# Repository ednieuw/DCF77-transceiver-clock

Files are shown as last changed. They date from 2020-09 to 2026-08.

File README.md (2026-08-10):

# DCF77 HC-12 Bluetooth transceiver clock

<table  border="0">
  <tr>
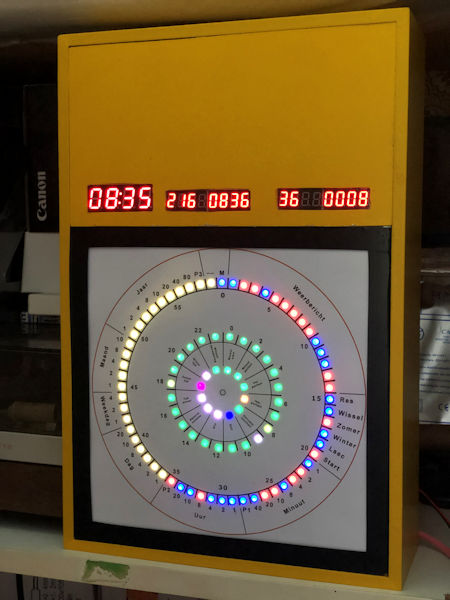
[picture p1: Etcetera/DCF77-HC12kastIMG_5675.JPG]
    <td></td>
    <td>
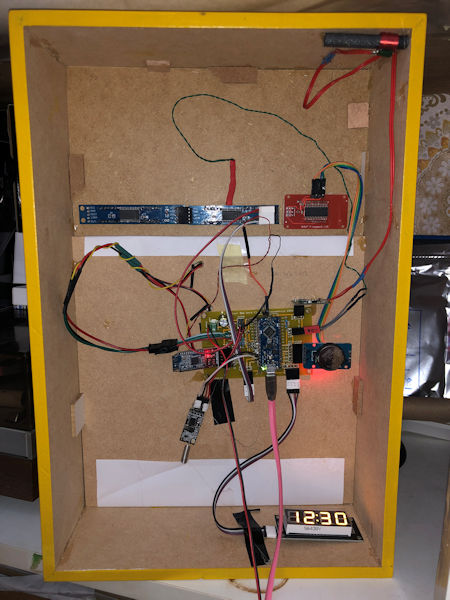
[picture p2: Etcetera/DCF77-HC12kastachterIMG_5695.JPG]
	</td>
  </tr>
  <tr class="auto-style1">
    <td>Front <span class="style7">(The colours of the LEDs are in real much more vivid) </span></td>
    <td>Inside the clock (3:55 hours later) <br>
    The DCF77-receiver hangs 10 cm away from the signal interfering LEDs and segment displays</td>
  </tr>
</table>
<p class="auto-style1"><strong>Introduction </strong></p>
<p class="auto-style1">This clock <a href="https://www.dcf77logs.de/live">decodes the DCF77-signal</a>, displays the received DCF77 bits and various information parameters in three WS2812 RGB-rings.<br>
  After decoding it sends the time as a string into the ether with a HC-12 433MHz Wireless Serial Transceiver.<br>
  with a Bluetooth module the clock can be controlled and statistics about the received signals retrieved 
  <br>
  The time is displayed with a 4-digit 7-segment
  HK16K33 and a 4-digit 7-segment
  I2C-TM1637  display.<br>
  (I prefer the TM1637 displays but bought the by accident HK16K33 displays.) <br>
  The received or calculated information is displayed with MAX7219 8-digits 7-segment displays. <br>
  <br>
  The software makes use of an algorithm that collects the readings without using interrupts (DCFNoInt) in contrast with the DCF77 Arduino library that uses interrupt to detect a pulse change. <br>
  In this DCFNoInt-program the processor is able to collect, in it spare time, over 30,000 
low or high signals.<br>
  In Mainflingen, Germany, a transmitter send on the long wave frequency of 77.5 KHz 
a signal that can be on or off (high or low). <br>
  Every second the signal is on for 0.1 second or 0.2 second.
That translates in respectively a 0 or 1 bit. <br>
The time is decoded in a <a href="https://en.wikipedia.org/wiki/Binary-coded_decimal">binary-coded decimal</a> format as shown in the picture below. </p>
<p class="auto-style1">
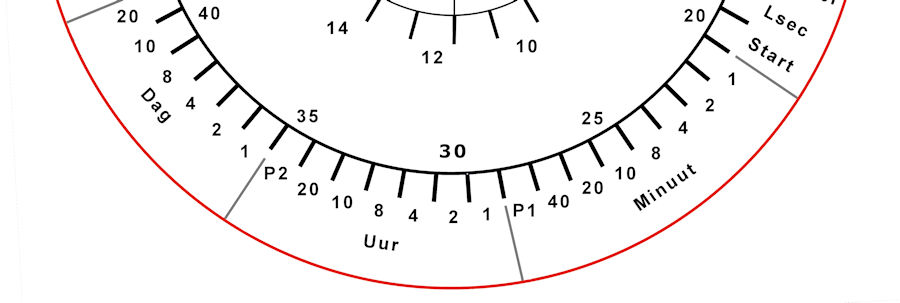
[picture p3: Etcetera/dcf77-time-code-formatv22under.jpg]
<br>
  <br>
  The DCFNoInt-algorithm is sensitive for long delays() in the code. The sample program demonstrates a method to avoid delays. <br>
  An advantage of this non-interrupt method is it smoothens spikes in the signal and does not require filtering because it takes an average of the received positive pulses. <br>
  Not all programs can be made 'uninterruptable' without long delays . Time consuming subroutines can make the pulse readings 
less usable.<br>
  The menu contains an option to read the pulses every x msec for y msec long. By playing with the x and y values the readings may be 
optimized for a program with long running subroutines. <br>
</p>
<table border="0" style="width: 628px">
  <tr>
    <td width="676" class="auto-style3">
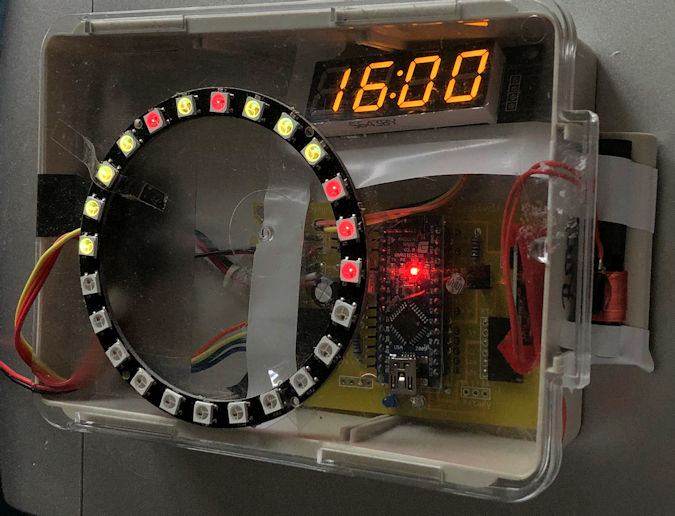
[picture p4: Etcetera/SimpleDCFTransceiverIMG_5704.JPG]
	</td>
  </tr>
  <tr>
    <td><span class="auto-style1">It is also possible to make a smaller unit with a 24 LED ring and a HC-12 transceiver. 
	<a>See </a> 
	<a href="https://github.com/ednieuw/DCF77_HC12">here 
	how</a> to make this receiver or modify this newer program V055 used for this 
	DCF77-transceiver. </span></td>
  </tr>
</table>
<p class="auto-style1">  The efficiency of the NoInt-method is comparable with the DCF77-library in the Arduino IDE from Thijs Ellenbaas. <br>
  With good reception both methods decode over 99%. <br>
  When reception is worse it depends on the signal. Sometimes the DCFNoInt-routine outperforms the interrupt routine by 50%.<br>
  The interrupt and non-interrupt methods are both used together in this program and increases the efficiency even further.<br>
In this program both received times must be identical before it is written to the optional RTC-module or internal Arduino clock.<br>
</p>
<table width="916" border="0">
  <tr>
    <td width="6">&nbsp;</td>
    <td width="900" class="auto-style1"><div align="center">
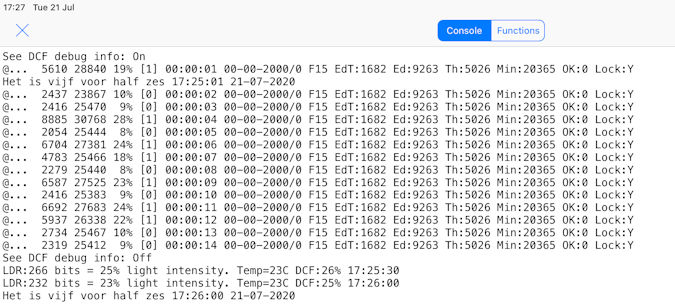
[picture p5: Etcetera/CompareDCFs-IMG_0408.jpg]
		</div></td>
  </tr>
  <tr>
    <td>&nbsp;</td>
    <td class="auto-style1">This is the result of a DCF77 receiver 5 cm away from WS2812 LEDs . <br>
    These LEDs  (but also the 7-segment displays) interferes the reception of the signal. From the 20365 minutes the original Arduino library (Th:) receives 5026 (25%) date/times correctly. The non interrupt 
	algorithm (Ed:) decodes 9263 (45%) times the date/time. EdT: are the 1682 proper times but not proper dates received. </td>
  </tr>
  <tr>
    <td>&nbsp;</td>
    <td class="auto-style1">Combined the proper received times exceeded 75% (not shown). That is 3 times better.<br>
	<br></td>
  </tr>
</table>
<p class="auto-style1"> <br>
  <strong>The Program</strong></p>
<p class="auto-style1">By turning on or off the #defines with a // in the program, one or both methods can be used.</p>
<pre class="style3">#define DCFMOD       // Use the Arduino DCF77 library with interrupts.
#define DCFTINY      // Use the DCFNoInt DCF algorithm in this program.
 </pre>
<span class="auto-style1">This is the heart of the algoritm; just counting the 
positive signals and the total received signals.</span><br>
 <pre class="style3"> SumSecondSignal += (!digitalRead(DCF_PIN));      // invert 0 to 1 and 1 to 0
 SumSignalCounts++;
    </pre>
<p class="auto-style1">After 995 milliseconds it waits for the positive signal to drop to zero. <br>
  </p>
<pre class="style3">if((millis() - DCFmsTick) &gt;995))     // Compute every second the received DCF-bit to a time 
 { 
 while (1-digitalRead(DCF_PIN))     // Avoid splitting a positive signal 
  {
   SumSignalCounts++;
   SumSecondSignal++;
  } </pre>
<p class="auto-style1">These few lines took  weeks of experimenting and solve why it lost every few minutes a good reception of the time.<br>
The internal Arduino clock drifts more than expected. 1 second in less than 10 minutes.<br>
In line 848 there is a correction possibility to make the calculation of the 
pulse percentage close to 10% and 20%.<br>The signal length can be seen in the 
serial monitor or Bluetooth connection with option A from the menu and of course 
on the clock it self.<br><br><span class="auto-style2">&nbsp;SumSignalCounts*=1.10;&nbsp;&nbsp;&nbsp;&nbsp; 
// Correction to correct pulses to an average of 100 and 200 msecs</span></p>
<p class="auto-style1">When the signal is decoded in line 913 a signal length 
between 5.1 and 16% is a 0 bit and between 16% and 32% a 1 bit.<br>No signal for 
a second is the start of a new minute and all other signal lengths are an error.
<br></p>
<pre>int msec  = (int)(1000 * SumSecondSignal / SumSignalCounts);                  // This are roughly the milliseconds times 10 of the signal length
 switch(msec)
  {
   case   0 ...  10: if (SumSignalCounts &gt; 50)                                 // Check if there were enough signals
                       {Bitpos = 59; Receivebitinfo = 2; Receivebit = 0; }     // If enough signals and one second no signal found. This is position zero
                              else { Receivebitinfo = 9; Receivebit = 0; }     // If not it is a bad signal probably a zero bit
                                                                        break; // If signal is less than 0.05 sec long than it is the start of minute signal
   case  11 ...  50: Receivebitinfo = 8; Receivebit = 0;                break; // In all other cases it is an error
   case  51 ... 160: Receivebitinfo = 0; Receivebit = 0;                break; // If signal is 0.1 sec long than it is a 0 
   case 161 ... 320: Receivebitinfo = 1; Receivebit = 1;                break; // If signal is 0.2 sec long than it is a 1 
   default:          Receivebitinfo = 9; Receivebit = 1;                break; // In all other cases it is an error probably a one bit
  }</pre>
<p class="auto-style1">Errors are flagged in the Receivebitinfo and the flag 
TimeSignaldoubtfull is set. When set the time/date is not reported. <br>The 
decoding routine returns TimeOk = 5 as result. <br>When TimeOK = 1 then the Date 
and time are correct. When TimeOk = 2 the date is possibly wrong but the time is 
OK and differs less than 2 minutes from the previous received time.</p>
<p class="auto-style1">Statistics are stored into EEPROM once a day at 0:00. <br>
Statistics can be seen from the menu with option S</p>
<p class="auto-style1">&nbsp;</p>
<p class="auto-style1">When A is pressed in the menu every second this line is 
printed</p>
<pre>@MH. 4181 36100 11% (0) 14:42:47 05-01-2000/6 F1 Ed:10943 Th:11094 Min:11717 OK:0 L:Y
@MH. 8905 37769 23% (1) 14:42:48 05-09-2000/6 F1 Ed:10943 Th:11094 Min:11717 OK:0 L:Y
@MH. 4095 36086 11% (0) 14:42:49 05-09-2000/6 F1 Ed:10943 Th:11094 Min:11717 OK:0 L:Y
@MH. 4286 36099 11% (0) 14:42:50 05-09-2000/6 F1 Ed:10943 Th:11094 Min:11717 OK:0 L:Y
@MH. 4424 36059 12% (0) 14:42:51 05-09-2000/6 F1 Ed:10943 Th:11094 Min:11717 OK:0 L:Y
@MH. 4150 36099 11% (0) 14:42:52 05-09-2000/6 F1 Ed:10943 Th:11094 Min:11717 OK:0 L:Y
@MH. 3992 36100 11% (0) 14:42:53 05-09-2000/6 F1 Ed:10943 Th:11094 Min:11717 OK:0 L:Y
@MH. 3831 36058 10% (0) 14:42:54 05-09-2000/6 F1 Ed:10943 Th:11094 Min:11717 OK:0 L:Y
@MH. 9440 38493 24% (1) 14:42:55 05-09-2020/6 F1 Ed:10943 Th:11094 Min:11717 OK:0 L:Y
@MH. 3783 36051 10% (0) 14:42:56 05-09-2020/6 F1 Ed:10943 Th:11094 Min:11717 OK:0 L:Y
a</pre>
<span class="auto-style1">When S is pressed</span><pre>s
----&gt; Statistics -----
DCFEd:10943                  <strong>DCFNoInt algorithm</strong> 
DCF77:11094                  <strong>DCF Arduino library</strong> 
Both:10537                   <strong>Identical time at the same minute </strong>
Valid times:11474            <strong>Valid times receive with both algorithms</strong> 
Total minutes:11717          <strong>Total time running</strong>
DCF Eff:97% Signal:99 DCF    <strong>Valid times in % and consecutive good minutes received (0-99) </strong>
0  1  2  3  4  5  6  7  8  9  10 11 12 13 14 15 16 17 18 19 20 21 22 23 -- Hour
60 60 60 60 60 60 58 60 58 60 56 58 58 54 60 60 58 60 56 58 58 53 60 55 <strong>-- Valid times NoInt</strong>
60 60 60 60 60 60 60 60 59 60 54 47 60 55 60 60 60 58 58 58 60 54 60 60 <strong>-- Valid times Int</strong>
03 03 04 03 03 05 00 03 04 02 03 07 03 17 01 01 02 05 03 01 03 02 02 03 <strong>-- Signal faults</strong>
1  2  3  4  5  6  7  8  9  10 11 12 13 14 15 16 17 18 19 20 21 22 23 24 25 26 27 28 29 30 31
56 57 57 57 00 00 00 00 00 00 00 00 00 00 00 00 00 00 00 00 00 00 00 00 00 00 00 00 00 00 00 
57 58 58 58 00 00 00 00 00 00 00 00 00 00 00 00 00 00 00 00 00 00 00 00 00 00 00 00 00 00 00 
05 03 03 02 00 00 00 00 00 00 00 00 00 00 00 00 00 00 00 00 00 00 00 00 00 00 00 00 00 00 00 
1  2  3  4  5  6  7  8  9  10 11 12
00 00 00 00 00 00 00 54 00 00 00 00 
00 00 00 00 00 00 00 55 00 00 00 00 
00 00 00 00 00 00 00 19 00 00 00 00 
0  1  2  3  4  5  6  7  8  9    Last 10 years (year modulo 10)
00 00 00 00 00 00 00 00 00 00 
00 00 00 00 00 00 00 00 00 00 
00 00 00 00 00 00 00 00 00 00 </pre>
<pre>
  DCF77 Lib OK --&gt; 14:42 05-09-2020                       <strong>The Arduino library decode a date/time</strong> 
TIME &amp; DATE OK --&gt; 14:42 05-09-2020                       <strong>The DCFNoInt algorithm decode a date/time</strong>
@L001|14:42:01 05-09-2020|DCF-eff:97% Signal:99 |DCF      <strong>Line sent with the HC-12</strong>
T144202                                                   <strong>Line sent with HC-12 to set time in my clocks</strong></pre>
<p class="auto-style1">After two years statistics are:</p>
<pre>----&gt; Statistics -----
DCFEd:855591
DCF77:785000
Both:759415
Valid times:878673
Total minutes:1006933
DCF Eff:87% Signal:99 DCF
0  1  2  3  4  5  6  7  8  9  10 11 12 13 14 15 16 17 18 19 20 21 22 23&nbsp;
60 58 58 58 60 56 60 60 58 60 58 60 60 54 56 58 60 60 56 58 00 00 00 42&nbsp;
60 60 60 60 60 60 60 60 60 60 60 60 60 60 60 60 60 60 60 60 00 00 00 43&nbsp;
02 04 02 03 01 03 04 00 05 00 04 02 05 03 02 01 03 04 03 02 00 00 00 03&nbsp;
1  2  3  4  5  6  7  8  9  10 11 12 13 14 15 16 17 18 19 20 21 22 23 24 25 26 27 28 29 30 31
58 59 58 58 57 56 42 00 00 00 00 00 00 00 00 00 00 00 00 00 00 00 00 00 00 00 00 00 00 00 00&nbsp;
59 60 59 59 59 57 43 00 00 00 00 00 00 00 00 00 00 00 00 00 00 00 00 00 00 00 00 00 00 00 00&nbsp;
03 02 03 02 02 05 03 00 00 00 00 00 00 00 00 00 00 00 00 00 00 00 00 00 00 00 00 00 00 00 00&nbsp;
1  2  3  4  5  6  7  8  9  10 11 12
57 56 57 57 57 57 57 58 58 56 56 56&nbsp;
57 52 48 57 57 58 58 58 58 55 56 56&nbsp;
07 08 07 05 08 04 06 06 03 07 05 08&nbsp;
&nbsp;0  1  2  3  4  5  6  7  8  9    Last 10 years (year modulo 10)
08 52 56 00 00 00 00 00 00 00&nbsp;
57 56 55 00 00 00 00 00 00 00&nbsp;
15 09 10 00 00 00 00 00 00 00&nbsp;</pre>
<p class="auto-style1">The DCF77 algorithm stopped working for some time and has 
a slightly lower score. After a restart of the clock the system worked again.<br>
Yesterday around 23h the MAX7219 display did not react anymore and a power down 
was needed.
</p>
<p class="auto-style1">&nbsp;</p>
<p class="auto-style1"><strong>The LEDs and Display</strong></p>
<table cellpadding="0" style="width: 640px">
	<tr>
		<td class="auto-style1" style="width: 644px">The DCFNoInt (DCFTINY in the define) algorithm was developed to drive the LEDs of the clock. <br>
  The clock contains three rings of 8, 24 and 60 LEDs. <br>
  The outer ring displays the received bits per minute. blue = 0 and red = 1. <br>
  The middle ring display the signal efficiency per hour and the current hour with a white LED. <br>
  The inner ring displays various parameters. </td>
		<td>
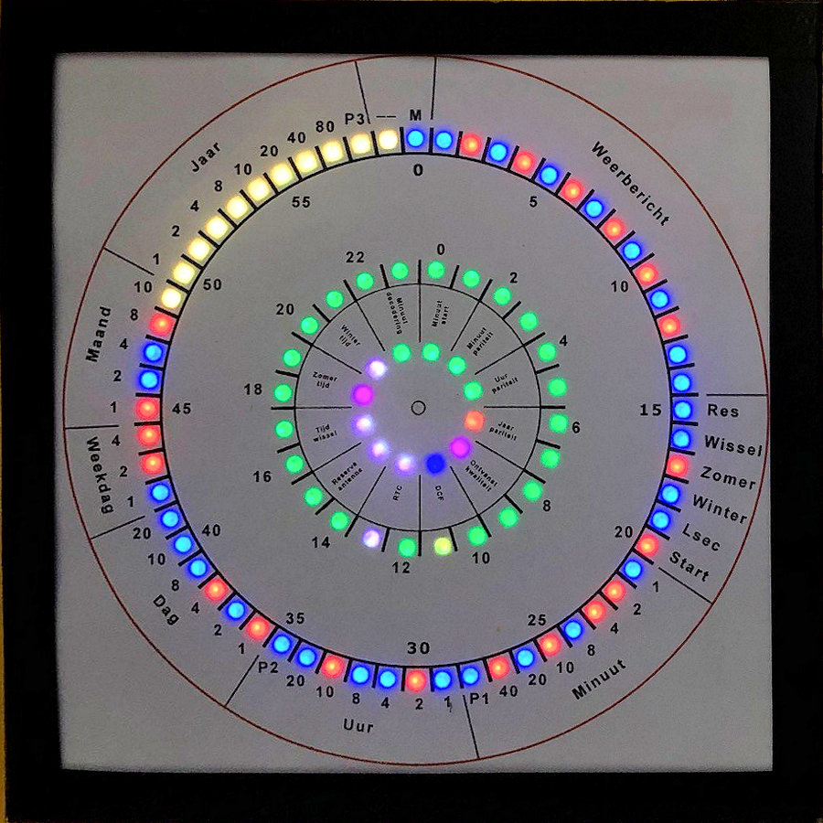
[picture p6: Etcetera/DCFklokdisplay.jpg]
DCF clock display
		</td>
	</tr>
	<tr>
		<td colspan="2"><a href="dcf77-time-code-formatv22small.jpg">
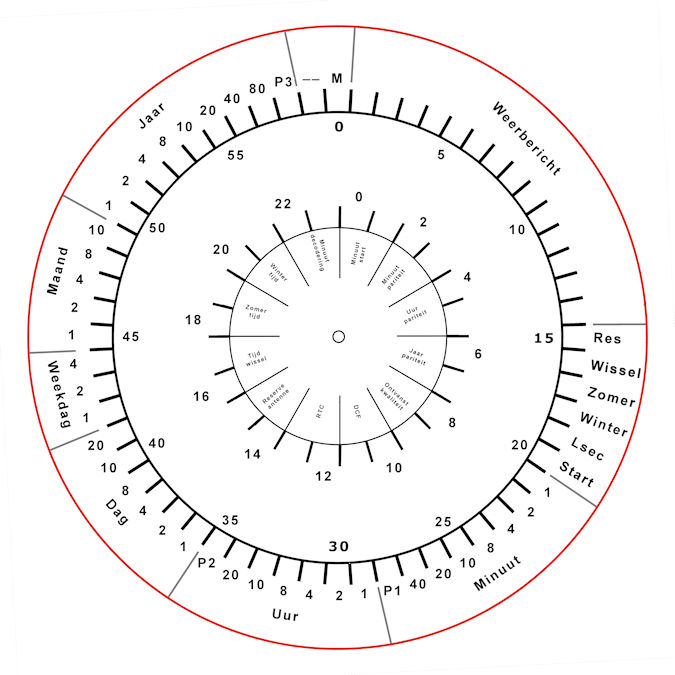
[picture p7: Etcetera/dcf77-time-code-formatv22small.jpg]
Small DCF77 clock display
		</a></td>
	</tr>
	<tr>
		<td class="auto-style1" colspan="2">Dutch design of the front display. I printed it on paper and placed it before the LEDs.</td>
	</tr>
</table>
<p class="auto-style1">  A TM1637 or HT16K33 display shows the current time. <br>
  A MAX7219 display is used to show the pulse width in msec, and the time as it is decoded by the algorithm <br>
  and the decoding efficiency in time as a percentage. <br>In the first seconds 
it displays the valid received times and total minutes it is running and then 
the date as 'ddmm'<br>After 20 seconds the right four digits are the bit 
received by the LDR that controls the light intensity of the LEDs.<br>So a lot 
of info and changing digits.</p>
<p class="auto-style1">  The time is transmitted at 433 MHz with a HC12 transceiver 
module.<br>The HC-12 can replace a Bluetooth module. They use the same baud rate 
of 9600 bps. Only the RX and TX lines are switched. <br>The coding to get the 
received characters from the module is identical. <br>&nbsp;<br>
  With a Bluetooth module connected the DCF77 clock can be operated with a phone.
<br>Search for "BLE HM-10 Terminal serial" for programs in the app stores of the 
phone<br>On a PC/laptop with Bluetooth a connection can also be set up.</p>
<p class="auto-style1"><strong>The Menu</strong></p>
<p class="auto-style1">The menu is as below and can be printed when entering the I in the serial monitor of the Arduino IDE<br>
or on a phone when connected with the Bluetooth module. </p>
<p class="style3 style4"> *** DCF HC12 Bluetooth Transmitter *** <br>
Enter time as: Thhmmss (T132145) <br>
A&nbsp; DCF debug info On/Off <br>
B&nbsp; Short DCF debug info On/Off <br>
C&nbsp; Clear statistics <br>
E&nbsp; Reset MAX7219 <br>
F&nbsp; Toggle full or interval DCFtiny readings <br>
G&nbsp; (G20) DCF loop measures every (0-999) msec <br>
H&nbsp; (H50) measurements in DCF loop (0-999) <br>
I&nbsp; For this info <br>
K&nbsp; Toggle HC12 transmission ON/OFF <br>
Lnn (L5) Min light intensity ( 1-255) <br>
Mnn (M90)Max light intensity (1%-250%) <br>
N&nbsp; (N2208)Turn On/OFF LEDs between Nhhhh <br>
O&nbsp; Turn Display ON/OFF <br>
R&nbsp; Reset <br>
S&nbsp; Print statistics<br>
------------------------------------------ 
<br>
&nbsp; &nbsp; Ed Nieuwenhuys sep-2020 <br>
&nbsp; Brightness Min:&nbsp; 4 bits Max:&nbsp; 15% <br>
&nbsp; &nbsp; LDR read Min:&nbsp; 0 bits Max: 187 bits <br>
&nbsp; DCF loop every:&nbsp; 5 msec&nbsp; for:&nbsp; 25 times <br>
LEDs off between: 22 - 08 <br>
------------------------------------------
<br>
Software version: V055 Station: L001 <br>
16:42:41 01-09-2020 </p>
<p class="auto-style1">&nbsp;</p>
<p class="auto-style1"><strong>The Electronics</strong></p>
<p class="auto-style1">An Arduino Nano Every is used to run the program. <br>
  <span class="style4">Sketch uses 35859 bytes (72%) of program storage space. Maximum is 49152 bytes.<br>
  Global variables use 1553 bytes (25%) of dynamic memory, leaving 4591 bytes for local variables. Maximum is 6144 bytes.</span><br>
</p>
<table width="200" border="0">
  <tr class="auto-style1">
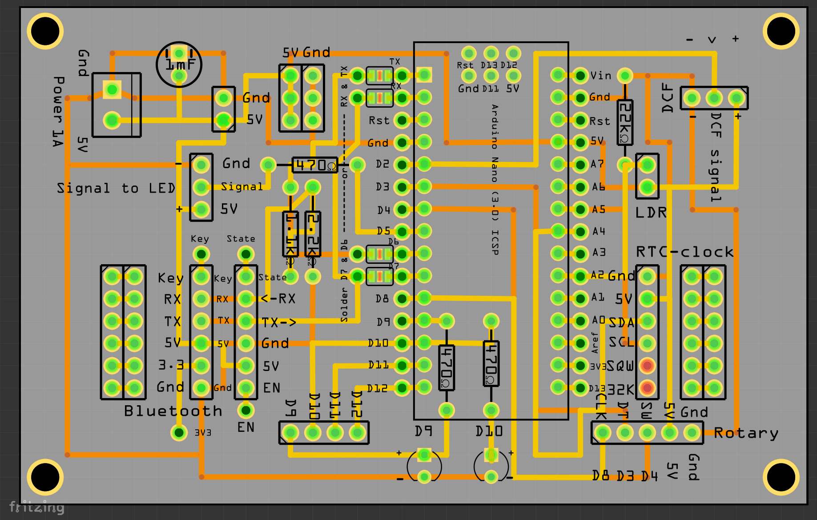
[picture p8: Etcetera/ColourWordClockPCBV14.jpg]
    <td colspan="2"></td>
  </tr>
  <tr class="auto-style1">
    <td width="298"><a href="Etcetera/Colour%2520Word%2520Clock%2520PCBV14.fzz">Fritzing design</a> of the PCB. </td>
    <td width="298">&nbsp;</td>
  </tr>
  <tr class="auto-style1">
    <td colspan="2"><p>&nbsp;</p>    </td>
  </tr>
</table>
<p><span class="auto-style1">The parts are connected to a PCB (designed for my 
Fibonacci and colour clocks). <br>
  A voltage divider with the 2.2 kOhm and 1.1 kOhm resistors lowers to voltage from 5V to 3.3V for the Bluetooth module<br>
The 470 Ohm resistors are used between the two LEDs and between the signal line of the WS2812 LEDs and the processor.<br>
The 22 kOhm resistor</span><span class="auto-style1"> gives good results with the GL5528 LDR photo resistor.<br>
A 1000 uF capacitor protects the circuit and the WS2812 LEDs against power spikes.<br>
There is no need for a rotary decoder and these pins are used to connect the TM1637 display.</span></p>
<pre class="style3">

The following pins are connected:
     // Digital hardware constants 

 DCF_PIN       = 2,  // DCFPulse on interrupt pin
 CLK_TM1637    = 3,  // PIN 3 TM1637Display
 DIO_TM1637    = 4,  // PIN 4 TM1637Display
 LED_PIN       = 5,  // LED rings on pin PIN 5
 BT_TX         = 6,  // Rx-pin on BT-mod to TX-pin on Arduino
 BT_RX         = 7,  // Tx-pin on BT-mod to RX-pin on Arduino 
 HC_12TX       = 8,  // RXD on HC-12 to TX Pin on Arduino 
 HC_12RX       = 9,  // TXD on HC-12 to RX Pin on Arduino
 MAX7219CLK    = 10, // MAX7219CLK
 MAX7219CS     = 11, // MAX7219CS 
 MAX7219DataIn = 12, // MAX7219DataIn
 DCF_LED_Pin   = 13  // Show DCF-signal
 };
 // Analog hardware constants ----
 EmptyA0       = 0, // A0
 EmptyA1       = 1, // A1
 PhotoCellPin  = 2, // A2 LDR
 EmptyA3       = 3, // A3
 SDA_pin       = 4, // SDA I2C pin for HT16K33 time display and DS3231 RTC clock module
 SCL_pin       = 5, // SCL I2C pin for HT16K33 time display and DS3231 RTC clock module
 EmptyA6       = 6, // Empty
 EmptyA7       = 7  // Empty </pre>
<p class="auto-style1">&nbsp;</p>
<p class="auto-style1"><br>
  More info about clocks and DCF77 here: <br>
  <a href="https://ednieuw.com/Woordklok/index.html">https://ednieuw.com/Woordklok/index.html </a> </p>
<p class="auto-style1">Ed Nieuwenhuys<br>
  13 September 2022<br><br>
</p>
<p class="auto-style1">&nbsp;</p>

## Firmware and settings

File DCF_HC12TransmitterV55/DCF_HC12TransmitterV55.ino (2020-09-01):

// =============================================================================================================================
/* 
This Arduino code works on a ATMEGA328 ( Nano Uno), ATMEGA1284 chip and Nano Every
This source contains code for the following modules:  
- RTC DS3231 clock module
- LDR light sensor 5528
- HC-12 Long Range Wireless Communication Module
- DCF77 module DCF-2
The DCF77 module reads the time and date from the German longwave DCF-77 time signal
The time and date are transmitted as ASCII-string as hhmmss. (031500 = 15 minutes past 3)
The date is hourly transmitted with a prefic D followed by ddmmyyyy ( D01042020 - 1 april 2020)
Comments are transmitted with a prefix @ (@ 10:07:38 09-01-2020 DCF:16)


V01 - V28 developing 
V029 Added Station and Version number as define. **To be done Added CRC in @ HC12 string 
V030 MAX72191 displays added 
V31 Added support for 24 Ws2812 ring for small transmitter S001. Added Dimleds()
V32 Stable version
V33 HC12 transceiver added
V34 Failed introduction of time functions
V35 Optimizing, efficiency in MAX7219
V36 Optimizing and refining, 
V37 stable version.  Added Interval measurements in DCFtiny, Store settings in EEPROM, added menu entries, 
    Corrected drifting and enhanced efficiency from 75% to >90% by changing > 999 in >= 1000 msec in DCFtine loop
V38a->z Optimized for BT communication on Nano every. second serial port does not receive? on Nano Every
V38b Minor changes  Ed:3429 Th:3520  Both:2490  Tot:5518 Last stable version
V38c Failure . HC12 and BT can not be used together. BT works when HC12 is removed. softwareserial lib?. Serial1 will not initialize
V38d https://mcudude.github.io/MegaCoreX/package_MCUdude_MegaCoreX_index.json
V38f Added ValidTimes
V38g Bluetooth on pin 6,7 HC12 on 8 and 12, pin 11 gets every second interfering false data 
V39  Stable version. moved Bluetooth- and Serialcheck to Everysecond subroutine. Readings went up from 10000 to 35000/s!
V40a Moved time calculation from Bitpos 59 to bitpos 0. Added statistics Ed:1052 Th:959 Both:901 Valid:1109 Tot:1173 
V40b Added EEPROM storage of Statistics  
V40c Tighter struct mem
V40d Get data from EEPROM at startup
V40e debugging   Ed:857 Th:1147 Min:1175
V41  >999msec changed to  if( Inow.second() != lastsecond)   . changed it back was very bad if((millis() - DCFmsTick) >999)
V41a to Reset MAX7219 added InitialyseMAX7219.
v42  Added menu entries 
V43  Succes! added at line 731; while (1-digitalRead(DCF_PIN)); --> Ed:609 Th:608 Min:614 
V44  In DCFclock L001 with one 7219 display 10-05-2020
V45  Optimizing 
V46  Added software reset from menu. Solved MegaCoreX compiler problem with DCF77. Added LEDs are off at night
V47  Added interrupt to pin0 and disabled it. Connect a wire between DCF pin 2 and pin 0 to use it. Minor changes in DCFlock and DCF signal use 
V48  Stable version
V49  Cleanup after extracting the code for DCF77-NoIntV01.ino
V50  Optimized time decoding from DCF   Identical to DCF77-NoIntV03. Added short Debuginfo possibility as menu entry B
V51  Corrected overflow in statistics counters
V52  Added HT16K33tijd
V53  Cleaned up, Changed and corrected DCFtiny counters
V53a LDR reading in display
V54  Final upload in L001 station
V55  Store valid time counters in EEPROM    

Ed Nieuwenhuys June 2020
 */
// ===============================================================================================================================

//--------------------------------------------
// ARDUINO Definition of installed modules
// If a module is not present remove it from compilation 
// by adding the comment slashes, //, before the #define
//--------------------------------------------
#define DCFMOD             // Use the Arduino DCF77 library with interrupts
#define DCFTINY            // Use the Tiny DCF algorithm in this program

#define HC12MOD            // Use HC12 time transreceiver Long Range Wireless Communication Module
#define BLUETOOTHMOD       // Use  this define if Bluetooth needs other pins than pin 0 and pin 1

//#define LCDMOD           // LCD 2 x 16 installed 
#define HT16K33tijd        // 4-digit HT16K33 time display installed https://www.adafruit.com/product/879 Adafruit GFX library 
#define TM1637tijd         // 4-digit TM1637 time display installed   TM1637 by Avishorp
#define MAX7219info        // MAX7219 display

#define MOD_DS3231         // DS3231 RTC module installed

//#define LED6812          // choose between LED type RGB=LED2812 or RGBW=LED6812
#define LED2812
//#define LEDs24RingInstalled

const byte NUMBEROF7219DISPLAYS = 2;       // 1 or 2. Second display chained with first one
char STATION[] = "L001";  
char VERSION[] = "V055";
//--------------------------------------------
// ARDUINO Includes defines and initialysations
//--------------------------------------------
                      #if defined LED2812 || defined LED6812
#define LEDsInstalled
                      #endif LED2812 || LED6812

#include <Wire.h>
#include <RTClib.h>
#include <avr/wdt.h>
#include <TimeLib.h>                             // For time management 
                     #if defined LEDsInstalled || defined LEDs24RingInstalled
#include <Adafruit_NeoPixel.h>
                     #endif LEDsInstalled
#include <EEPROM.h>
                     #ifdef LCDMOD
#include <LCD.h>
#include <LiquidCrystal_I2C.h>
                     #endif LCDMOD
                     #ifdef DCFMOD
#include <DCF77.h>
                     #endif DCFMOD
                     #ifdef BLUETOOTHMOD
#include <SoftwareSerial.h>        // Arduino     // for Bluetooth communication
                     #endif BLUETOOTHMOD
                     #ifdef HC12MOD
#include <SoftwareSerial.h>                       // For HC12
                     #endif HC12MOD 
                     #ifdef TM1637tijd 
#include <TM1637Display.h>
                     #endif TM1637tijd 
                     #ifdef HT16K33tijd
#include <Adafruit_GFX.h>
#include "Adafruit_LEDBackpack.h"                //https://learn.adafruit.com/adafruit-led-backpack/overview?view=all
                     #endif HT16K33tijd
                     #ifdef MAX7219info
#include <LedControl.h> 
                      #endif MAX7219info 
//--------------------------------------------
// PIN Assigments
//--------------------------------------------                      
enum DigitalPinAssignments {      // Digital hardware constants ATMEGA 328 ----

 DCFgood      = 1,                 // DCF-signal > 50
 secondsPin   = 1,                 // Seconds
 Interrupt0   = 0,                 // Interrupt0
 DCF_PIN      = 2,                 // DCFPulse on interrupt pin
 CLK_TM1637   = 3,                 // PIN 3 TM1637Display
 DIO_TM1637   = 4,                 // PIN 4 TM1637Display
 LED_PIN      = 5,                 // LED rings on pin PIN 5
 BT_TX        = 6,                 // Rx-pin on BT-mod to TX-pin on Arduino
 BT_RX        = 7,                 // Tx-pin on BT-mod to RX-pin on Arduino   
 HC_12TX      = 8,                 // RXD on HC-12 to TX Pin on Arduino  
 HC_12RX      = 9,                 // TXD on HC-12 to RX Pin on Arduino
 MAX7219CLK   = 10,                // MAX7219CLK
 MAX7219CS    = 11,                // MAX7219CS 
 MAX7219DataIn= 12,                // MAX7219DataIn
 DCF_LED_Pin  = 13                 // Show DCF-signal
 };
 
enum AnalogPinAssignments {     // Analog hardware constants ----
 EmptyA0      = 0,                // A0
 EmptyA1      = 1,                // A1
 PhotoCellPin = 2,                // A2
 EmptyA3      = 3,                // A3
 SDA_pin      = 4,                // SDA pin
 SCL_pin      = 5,                // SCL pin
 EmptyA6      = 6,                // Empty
 EmptyA7      = 7};               // Empty

//--------------------------------------------
// COLOURS
//--------------------------------------------   
                         #ifdef LED2812
const uint32_t white     = 0x00FFFFFF;                     // White is R, G and B on WS2812                
                         #endif LED2812
                         #ifdef LED6812    
const uint32_t white     = 0xFF000000;                     // The SK6812 LED has a white LED that is pure white
                         #endif LED6812  
const uint32_t black  = 0x000000, red   = 0xFF0000, orange = 0xFF7000;
const uint32_t yellow = 0xFFFF00, apple = 0x80FF00, brown  = 0x503000;
const uint32_t green  = 0x00FF00, grass = 0x00FF80, sky    = 0x00FFFF;
const uint32_t marine = 0x0080FF, blue  = 0x0000FF, pink   = 0xFF0080; 
const uint32_t purple = 0xFF00FF, softwhite = 0x606060;

//--------------------------------------------
// LED
//--------------------------------------------
bool LEDsAreOff = false;                                   // If true LEDs are off except time display
                      #ifdef LEDsInstalled
                         #ifdef LED6812 
const byte NUM_LEDS  = 96;                                 // How many leds in  strip?   
Adafruit_NeoPixel strip = Adafruit_NeoPixel(NUM_LEDS, LED_PIN, NEO_GRBW + NEO_KHZ800);  //NEO_RGBW
                         #endif LED6812  
                         #ifdef LED2812
const byte NUM_LEDS  = 96;                                 // How many leds in  strip?
Adafruit_NeoPixel strip = Adafruit_NeoPixel(NUM_LEDS, LED_PIN, NEO_GRB + NEO_KHZ800);  //NEO_RGB NEO_GRB
                         #endif LED2812
                      #endif LEDsInstalled
                         #ifdef LEDs24RingInstalled
const byte NUM_LEDS  = 24;                                 // How many leds in  strip?
const uint32_t white = 0x00FFFFFF;  
Adafruit_NeoPixel strip = Adafruit_NeoPixel(NUM_LEDS, LED_PIN, NEO_GRB + NEO_KHZ800);  //NEO_RGB NEO_GRB
                         #endif LEDs24RingInstalled                     

//--------------------------------------------
// HC-12 Long Range Wireless Communication Module
//--------------------------------------------
                         #ifdef HC12MOD
SoftwareSerial HC12(HC_12RX, HC_12TX); 
bool HC12transmit = true;                                   // If false HC12 does not transmits
                         #endif HC12MOD 
//--------------------------------------------
// BLUETOOTH
//--------------------------------------------                                     
                           #ifdef BLUETOOTHMOD
SoftwareSerial Bluetooth(BT_RX, BT_TX);                     // BT_RX <=> TXD on BT module, BT_TX <=> RXD on BT module
bool    BluetoothConnected = false;
String  BluetoothString;
                           #endif BLUETOOTHMOD 
//--------------------------------------------
// CLOCK
//--------------------------------------------                                 
#define MAXTEXT 110                                         // The maximum length of sptext in de sprintf function
static  uint32_t msTick;                                    // The number of millisecond ticks since we last incremented the second counter
int       Isecond, Iminute, Ihour, Iday, Imonth, Iyear; 
int       Dsecond, Dminute, Dhour, Dday, Dmonth, Dyear, Dwday; 
byte      lastminute, lasthour, lastday, lastmonth, lastyear, sayhour = 0;
byte      SecPulse  = 0;                                    // Give a pulse to the Isecond led

const byte MenuItems = 18;                                  // No of entries in menu
const char menu[][50] PROGMEM = {
 "*** DCF HC12 Bluetooth Transmitter ***",
 "Enter time as: Thhmmss (T132145)",
 "A   DCF debug info On/Off",
 "B   Short DCF debug info On/Off",
 "C   Clear statistics",  
// "D   D15122017 for date 15 December 2017",
 "E   Reset MAX7219",
 "F   Toggle full or interval DCFtiny readings", 
 "G   (G20) DCF loop measures every (0-999) msec",
 "H   (H50) mesurements in DCF loop (0-999)",
 "I   For this info",
 "K   Toggle HC12 transmission ON/OFF",
 "Lnn (L5) Min light intensity ( 1-255)",
 "Mnn (M90)Max light intensity (1%-250%)",
 "N   (N2208)Turn On/OFF LEDs between Nhhhh",
 "O   Turn Display ON/OFF",
 "R   Reset",
 "S   Print statistics",
// "T   T091512 is time 09:15:12",
  "    Ed Nieuwenhuys sep-2020" };

//--------------------------------------------
// LDR PHOTOCELL
//--------------------------------------------
const byte MAXBRIGHTNESS    = 15;
const byte LOWBRIGHTNESS    = 4;
byte  LightReducer          =  MAXBRIGHTNESS;              // Factor (%) to dim LED intensity with. Between 1% and 250%
byte  LowerBrightness       =  LOWBRIGHTNESS;              // Lower limit of Brightness ( 0 - 255)
byte  BrightnessCalcFromLDR = 64;                          // Corrected brighness (0-255) 
int   MinPhotocell          = 999;                         // stores minimum reading of photocell;
int   MaxPhotocell          = 1;                           // stores maximum reading of photocell;
int   LDRvalue;
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
void loop(void)
{ 
 EverySecondCheck();
                              #if defined DCFMOD || defined DCFTINY        
 DCF77Check();
                              #endif DCFMOD || defined DCFTINY
}  
//--------------------------------------------
// ARDUINO Setup
//--------------------------------------------
void setup()
{                                        
 Serial.begin(9600);                                                          // Setup the serial port to 9600 baud                                                        // Start the RTC-module  
 while (!Serial);                                                             // wait for serial port to connect. Needed for native USB port only
 Tekstprintln("\n*********\nSerial started"); 
                              #ifdef ARDUINO_AVR_NANO_EVERY
 Tekstprintln("Compiled for ARDUINO_AVR_NANO_EVERY");
                              #endif
                              #if defined(ARDUINO_SAMD_MKRWIFI1010)
 Tekstprintln("Compiled for ARDUINO_SAMD_MKRWIFI1010");                             
                              #endif 
 Wire.begin();                                                                // Start communication with I2C / TWI devices                            
 pinMode(DCF_LED_Pin, OUTPUT);                                                // For showing DCF-pulse or other purposes
 pinMode(DCF_PIN,     INPUT_PULLUP);
 pinMode(Interrupt0,  INPUT_PULLUP);
 pinMode(DCFgood,     OUTPUT );  
 pinMode(secondsPin,  OUTPUT );
                              #ifdef MOD_DS3231
 RTCklok.begin();                                                             // start the RTC-module
                              # else if 
 RTCklok.begin(DateTime(F(__DATE__), F(__TIME__)));                           // if no RTC module is installed use the ATMEGAchip clock
                              #endif MOD_DS3231  
                              #ifdef DCFMOD
 DCF.Start();                                                                 // Start the DCF-module
 Tekstprintln("DCF77 enabled");
                              #endif DCFMOD
                              #ifdef LCDMOD
 lcd.begin (16,2); // for 16 x 2 LCD module                                   // Activate LCD module
 lcd.setBacklightPin(3,POSITIVE);
 lcd.setBacklight(HIGH);
 Tekstprintln("LCD enabled");
                              #endif LCDMOD
                              #ifdef TM1637tijd                               // 4-digit time display installed
 Tijd_display.setBrightness(3);                                               // Set the display brightness (0-7):
 Tijd_display.clear();
 Tekstprintln("4-digit time TM1637 display installed"); 
                              #endif TM1637tijd  
                              #ifdef HT16K33tijd
 Tijd_displayIC2.begin(0x70);
 Tijd_displayIC2.setBrightness(3);                                            // Set the display brightness (0-7):
 Tekstprintln("4-digit time HT16K33 display installed"); 
                              #endif HT16K33tijd
                              #ifdef LEDsInstalled
                                  // --- LED
 strip.begin();
 strip.setBrightness(LightReducer); //BRIGHTNESS);
 LedsOff();                                                                   // Initialize all pixels to 'off' 
 ColorLeds("", 60, 84, purple);                                               // fill the middle ring with purple dots
 LedsOffOuterring();
 
 ShowLeds(); 
                              #ifdef LED6812    
 Tekstprintln("LEDs SK6812 enabled");
                              #endif LED6812  
                              #ifdef LED2812
 Tekstprintln("LEDs WS2812 enabled");
                              #endif LED2812
   
                                 // --- LED 
                              #endif LEDsInstalled  
                              #ifdef LEDs24RingInstalled
 strip.begin();
 strip.setBrightness(LightReducer); //BRIGHTNESS);
 LedsOff();                                                                   // Initialize all pixels to 'off' 
 Tekstprintln("24 LED ring enabled"); 
                              #endif LEDs24RingInstalled
                              #ifdef BLUETOOTHMOD 
                              #if defined(ARDUINO_SAMD_MKRWIFI1010)           // || defined (ARDUINO_AVR_NANO_EVERY)  
 Serial1.begin(9600); 
 Tekstprintln("Bluetooth MKR enabled"); // Bluetooth connected to Serial1
                              #else if
 Bluetooth.begin(9600); 
 Tekstprintln("Bluetooth enabled"); 
                              #endif ARDUINO_SAMD_MKRWIFI1010
                              #endif BLUETOOTHMOD
                              #ifdef HC12MOD
 HC12.begin(9600);               // Serial port to HC12
 Tekstprintln("HC-12 time sender enabled");
                             #endif HC12MOD 
                             #ifdef MAX7219info                     
 InitialyseMAX7219();
  sprintf(sptext, "123 567887654321");  PrintStringToSegDisplay(sptext);         
 Tekstprintln("MAX7219info enabled");     
 lc.clearDisplay(0);
 lc.clearDisplay(1); 
                              #endif MAX7219info    
 DateTime now        = RTCklok.now();
 DateTime compiled   = DateTime(__DATE__, __TIME__);
 if (now.unixtime() < compiled.unixtime()) 
  {
   Serial.println(F("RTC is older than compile time! Updating"));             // Following line sets the RTC to the date & time this sketch was compiled
   RTCklok.adjust(DateTime(F(__DATE__), F(__TIME__))); 
  }
 EEPROM.get(0,Mem);                                                          // Get the data from EEPROM
                                                                             // Store the EEPROM values in work variables
 Ed                = Mem.Ed;                                                 // Counter of total valid times since start for DCFtiny 
 Thijs             = Mem.Thijs;                                              // Counter of totalvalid times since start for DCF77
 EdTh              = Mem.EdTh;                                               // Valid times per minute counters for DCFtiny and DCF77
 ValidTimes        = Mem.ValidTimes;                                         // Counter of total recorded valid times
 MinutesSinceStart = Mem.MinutesSinceStart;                                  // Counter of recorded valid and not valid times
 SWversion();                                                                // Display the version number of the software
 GetTijd(0);                                                                 // Get the time and store it in the proper variables (Ihour,Iday etc.)
 setTime(Ihour, Iminute, Isecond,Iyear, Imonth, Iday);
 lasthour  = Ihour;
 lastday   = Iday;
 lastmonth = Imonth;
 lastyear  = Iyear;
 //attachInterrupt(digitalPinToInterrupt(Interrupt0), FuncInterrupt0, CHANGE);
 DCFmsTick = millis();                                                        // Start of DCF 1 second loop
 msTick = millis();                                                           // Used in KY-040 rotary for debouncing and seconds check

 } 
//--------------------------------------------
// CLOCK Version info
//--------------------------------------------
void SWversion(void) 
{ 
 for (int n=0; n<52; n++) Serial.print("_");                                                Serial.println();
 for (int i = 0; i <MenuItems; i++)   {strcpy_P(sptext, menu[i]);                           Tekstprintln(sptext);  }
 for (int n=0; n<52; n++) {Serial.print(F("_"));}                                           Serial.println();
 sprintf(sptext,"  Brightness Min: %3d bits Max: %3d%%",LowerBrightness, LightReducer);     Tekstprintln(sptext);
 sprintf(sptext,"    LDR read Min: %3d bits Max: %3d bits",MinPhotocell, MaxPhotocell);     Tekstprintln(sptext);
 sprintf(sptext,"  DCF loop every: %3d msec  for: %3d times",mSecInterval, DCFreadsInLoop); Tekstprintln(sptext);
 sprintf(sptext,"LEDs off between: %0.2d - %0.2d",Mem.TurnOffLEDsAtHH, Mem.TurnOnLEDsAtHH); Tekstprintln(sptext);
 sprintf(sptext,"Software version: %s Station: %s",VERSION,STATION);                        Tekstprintln(sptext); 
 GetTijd(1);  
 for (int n=0; n<52; n++) Serial.print("_");                                                Serial.println();
}
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

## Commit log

2020-05-22 Version V49
    This Arduino code works on a ATMEGA328 ( Nano Uno), ATMEGA1284 chip and Nano Every
    This source contains code for the following modules:
    - RTC DS3231 clock module
    - LDR light sensor 5528
    - HC-12 Long Range Wireless Communication Module
    - DCF77 module DCF-2
    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
2020-06-13 Software stable.
    The hardware is waiting for a nice case
2021-04-16 Bugfixes
    V56 Added counters for wrong times reported by both decoding methods DCF77 and DCFTiny
    V57 Removed compiler warnings Changed Mem.mSecInterval !!Not checked yet
    [DCF_HC12TransmitterV57.ino]
